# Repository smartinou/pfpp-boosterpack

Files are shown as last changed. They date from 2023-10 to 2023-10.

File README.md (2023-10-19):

# pfpp-rtcc-boosterpack
A boosterpack-compatible board for pfpp project.

This board holds a battery-backup'ed precision RTCC. It's main duty is to keep the time of the day and manage alarms that are set for feeding your pet.

on top of an RTCC, it also holds a MicroSD card cage, and a TB6612 motor controller. The MicroSD card can be used for logging events. The motor controller is used to activate the feeder.

This project was originally built for the EK-TM4C129EXL development board, on boosterpack2 location. It should work on any BoosterPack-compatible interface.

## GPIO Mapping

GPIO match for various development boards.

### EK-TM4C129EXL

J1
Pin | MCU Pin | BoosterPack Schematic
--- | --- | ---
1 | +3.3V | +3.3V
2 | PD2 | NC
3 | PP0 | NC
4 | PP1 | NC
5 | See JP4 | SPI_SDC_CSn
6 | See JP5 | NC
7 | PQ0 | SPI_CLK
8 | PP4 | NC
9 | PN5 | NC
10 | PN4 | NC

J2
Pin | MCU Pin | BoosterPack Schematic
--- | --- | ---
1 | GND | GND
2 | PM7 | NC
3 | PP5 | NC
4 | PA7 | SD_DET
5 | Reset | NC
6 | PQ2/PA3 | SPI_MOSI
7 | PQ3/PA2 | SPI_MISO
8 | PP3 | RTCC_INTn
9 | PQ1 | SPI_RTCC_CSn
10 | PM6 | AIN2

J3
Pin | MCU Pin | BoosterPack Schematic
--- | --- | ---
1 | +5V | NC
2 | GND | GND
3 | PB4 | NC
4 | PB5 | NC
5 | PK0 | NC
6 | PK1 | NC
7 | PK2 | NC
8 | PK3 | NC
9 | PA4 | NC
10 | PA5 | NC

J4
Pin | MCU Pin | BoosterPack Schematic
--- | --- | ---
1 | PG1 | PWMB
2 | PK4 | PWMA
3 | PK5 | NC
4 | PM0 | NC
5 | PM1 | NC
6 | PM2 | BIN2
7 | PH0 | BIN1
8 | PH1 | STBYn
9 | PK6 | AIN1
10 | PK7 | RTCC_RST

### EK-TM4C123GXL

**Even if the board was 1st developed for the EK-TM4C129EXL, the GPIO pin matching for the EK-TM4C123GXL corresponds to the symbols in the schematic.**

Pin | J1 MCU Pin | J1 BoosterPack Schematic | J3 MCU Pin | J3 BoosterPack Schematic
--- | --- | --- | --- | ---
1 | +3.3V | +3.3V | +5V | NC
2 | PB5 | NC | GND | GND
3 | PB0 | NC | PB4 | NC
4 | PB1 | NC | PB5 | NC
5 | PE4 | SPI_SDC_CSn | PK0 | NC
6 | PE5 | NC | PK1 | NC
7 | PB4 | SPI_CLK | PK2 | NC
8 | PA5 | NC | PK3 | NC
9 | PA6 | NC | PA4 | NC
10 | PA6 | NC | PA5 | NC

Pin | J4 MCU Pin | J4 BoosterPack Schematic | J2 MCU Pin | J2 BoosterPack Schematic
--- | --- | --- | --- | ---
1 | PF2 | PWMB | GND | GND
2 | PF3 | PWMA | PB2 | NC
3 | PB3 | NC | PB0 | NC
4 | PC4 | NC | PF0 | SD_DET
5 | PC5 | NC | Reset | NC
6 | PC6 | BIN2 | PB7 | SPI_MOSI
7 | PC7 | BIN1 | PB6 | SPI_MISO
8 | PD6 | STBYn | PA4 | RTCC_INTn
9 | PD7 | AIN1 | PA3 | SPI_RTCC_CSn
10 | PC4 | RTCC_RST | PA2 | AIN2

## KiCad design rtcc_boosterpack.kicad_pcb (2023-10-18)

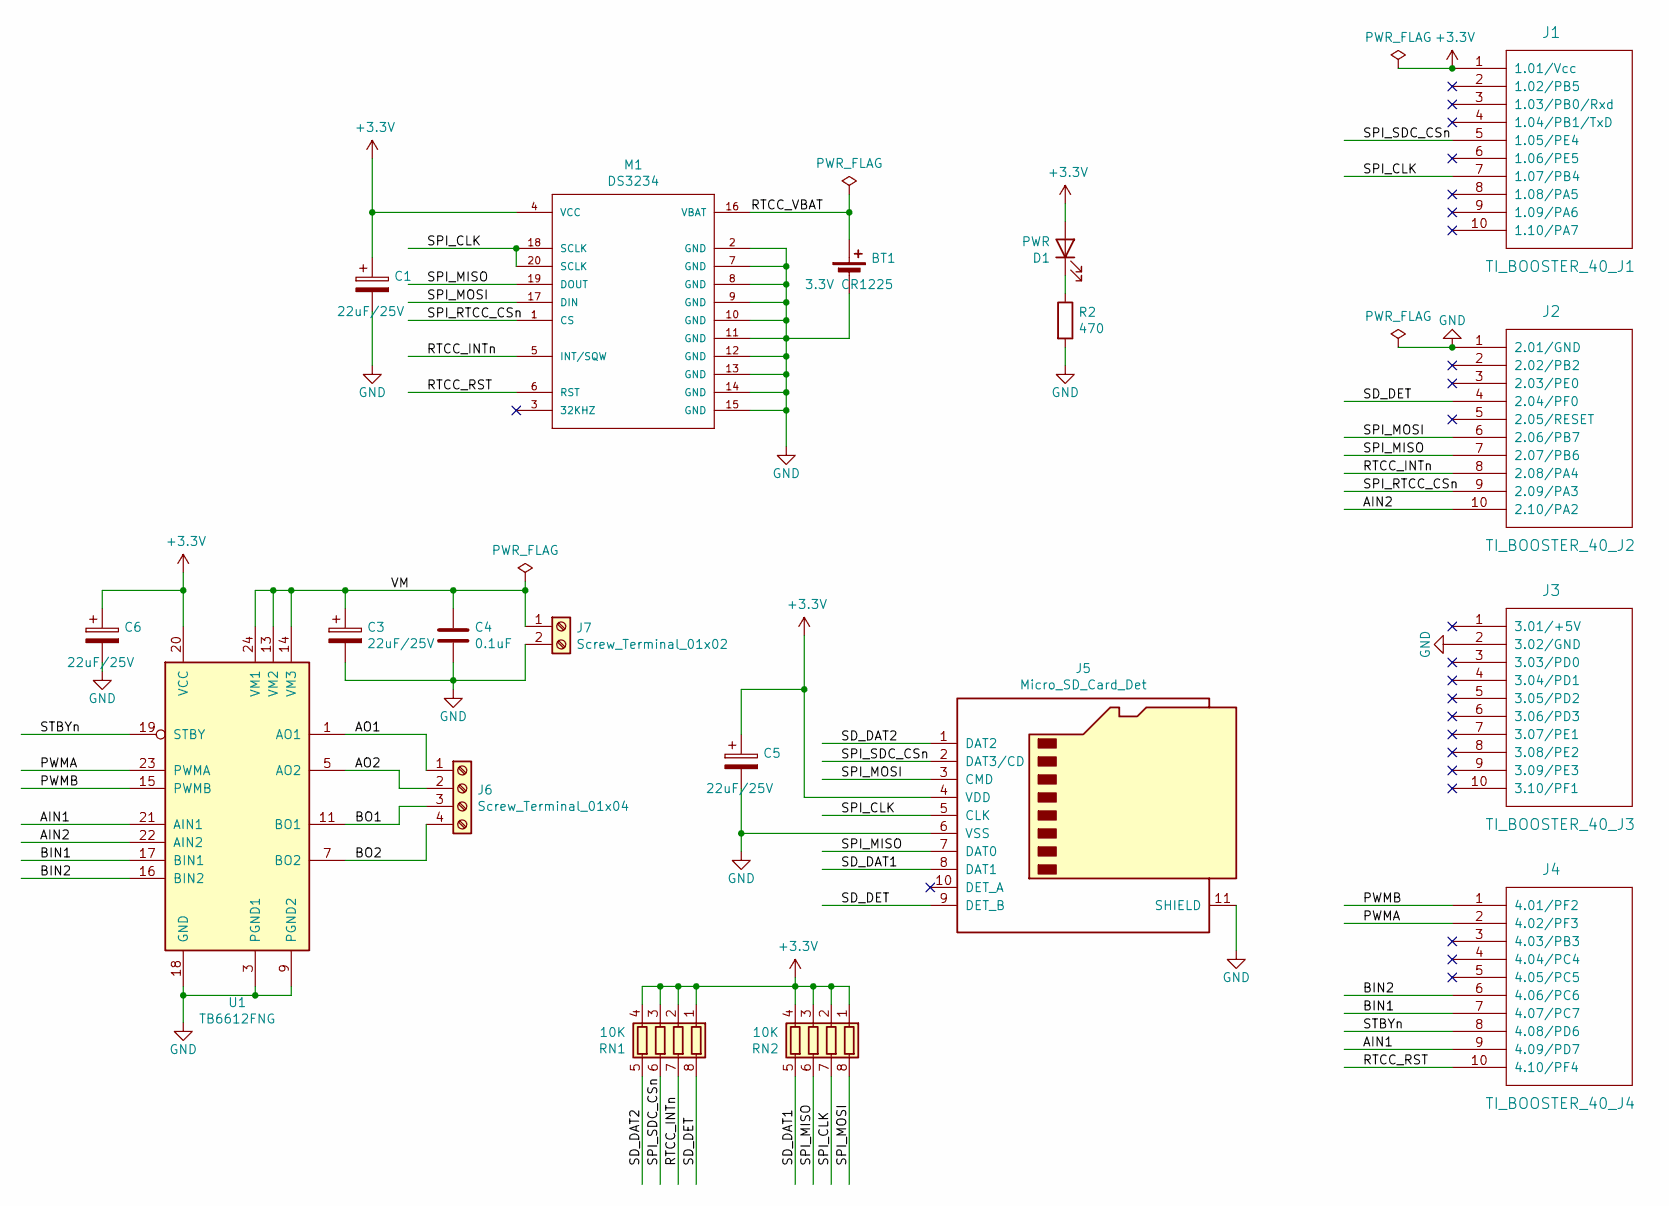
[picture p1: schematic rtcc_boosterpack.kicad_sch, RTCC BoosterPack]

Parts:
BT1: 3.3V CR1225; BatteryHolder_Keystone_3000_1x12mm; LCSC N/A
C1, C3, C5, C6: 22uF/25V; C_0805_2012Metric_Pad1.18x1.45mm_HandSolder; LCSC C45783
C4: 0.1uF; C_0603_1608Metric_Pad1.08x0.95mm_HandSolder; LCSC C14663
D1: PWR; LED_0603_1608Metric_Pad1.05x0.95mm_HandSolder; LCSC C2286
J1: TI_BOOSTER_40_J1; PinHeader_1x10_P2.54mm_Vertical; LCSC N/A
J2: TI_BOOSTER_40_J2; PinHeader_1x10_P2.54mm_Vertical; LCSC N/A
J3: TI_BOOSTER_40_J3; PinHeader_1x10_P2.54mm_Vertical; LCSC N/A
J4: TI_BOOSTER_40_J4; PinHeader_1x10_P2.54mm_Vertical; LCSC N/A
J5: Micro_SD_Card_Det; SF-MICRO-SD-PFPP; LCSC C105419
J6: Screw_Terminal_01x04; TerminalBlock_TE_282834-4_1x04_P2.54mm_Horizontal; LCSC C474922
J7: Screw_Terminal_01x02; TerminalBlock_TE_282834-2_1x02_P2.54mm_Horizontal; LCSC C474920
M1: DS3234; SOP-20_7.5x12.8mm_P1.27mm; LCSC C143318
R2: 470; R_0603_1608Metric_Pad0.98x0.95mm_HandSolder; LCSC C23179
RN1, RN2: 10K; R_Array_Convex_4x0603; LCSC C29718
U1: TB6612FNG; TSSOP-24_6.1x7.8mm_P0.65mm; LCSC C141517

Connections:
+3V3: C1.1, C5.1, C6.1, D1.2 (A), J1.1 (1.01/Vcc), J5.4 (VDD), M1.4 (VCC), RN1.1 (R1.1), RN1.2 (R2.1), RN1.3 (R3.1), RN1.4 (R4.1), RN2.1 (R1.1), RN2.2 (R2.1), RN2.3 (R3.1), RN2.4 (R4.1), U1.20 (VCC)
/AIN1: J4.9 (4.09/PD7), U1.21 (AIN1)
/AIN2: J2.10 (2.10/PA2), U1.22 (AIN2)
/AO1: J6.1, U1.1 (AO1), U1.2 (AO1)
/AO2: J6.2, U1.5 (AO2), U1.6 (AO2)
/BIN1: J4.7 (4.07/PC7), U1.17 (BIN1)
/BIN2: J4.6 (4.06/PC6), U1.16 (BIN2)
/BO1: J6.3, U1.11 (BO1), U1.12 (BO1)
/BO2: J6.4, U1.7 (BO2), U1.8 (BO2)
/PWMA: J4.2 (4.02/PF3), U1.23 (PWMA)
/PWMB: J4.1 (4.01/PF2), U1.15 (PWMB)
/RTCC_INTn: J2.8 (2.08/PA4), M1.5 (INT/SQW), RN1.7 (R2.2)
/RTCC_RST: J4.10 (4.10/PF4), M1.6 (RST)
/RTCC_VBAT: BT1.1 (+), M1.16 (VBAT)
/SD_DAT1: J5.8 (DAT1), RN2.5 (R4.2)
/SD_DAT2: J5.1 (DAT2), RN1.5 (R4.2)
/SD_DET: J2.4 (2.04/PF0), J5.9 (DET_B), RN1.8 (R1.2)
/SPI_CLK: J1.7 (1.07/PB4), J5.5 (CLK), M1.18 (SCLK), M1.20 (SCLK), RN2.7 (R2.2)
/SPI_MISO: J2.7 (2.07/PB6), J5.7 (DAT0), M1.19 (DOUT), RN2.6 (R3.2)
/SPI_MOSI: J2.6 (2.06/PB7), J5.3 (CMD), M1.17 (DIN), RN2.8 (R1.2)
/SPI_RTCC_CSn: J2.9 (2.09/PA3), M1.1 (CS)
/SPI_SDC_CSn: J1.5 (1.05/PE4), J5.2 (DAT3/CD), RN1.6 (R3.2)
/STBYn: J4.8 (4.08/PD6), U1.19 (STBY)
/VM: C3.1, C4.1, J7.1, U1.13 (VM2), U1.14 (VM3), U1.24 (VM1)
GND: BT1.2 (-), C1.2, C3.2, C4.2, C5.2, C6.2, J2.1 (2.01/GND), J3.2 (3.02/GND), J5.6 (VSS), J5.11 (SHIELD), J7.2, M1.2 (GND), M1.7 (GND), M1.8 (GND), M1.9 (GND), M1.10 (GND), M1.11 (GND), M1.12 (GND), M1.13 (GND), M1.14 (GND), M1.15 (GND), R2.2, U1.3 (PGND1), U1.4 (PGND1), U1.9 (PGND2), U1.10 (PGND2), U1.18 (GND)
unnamed: D1.1 (K), R2.1

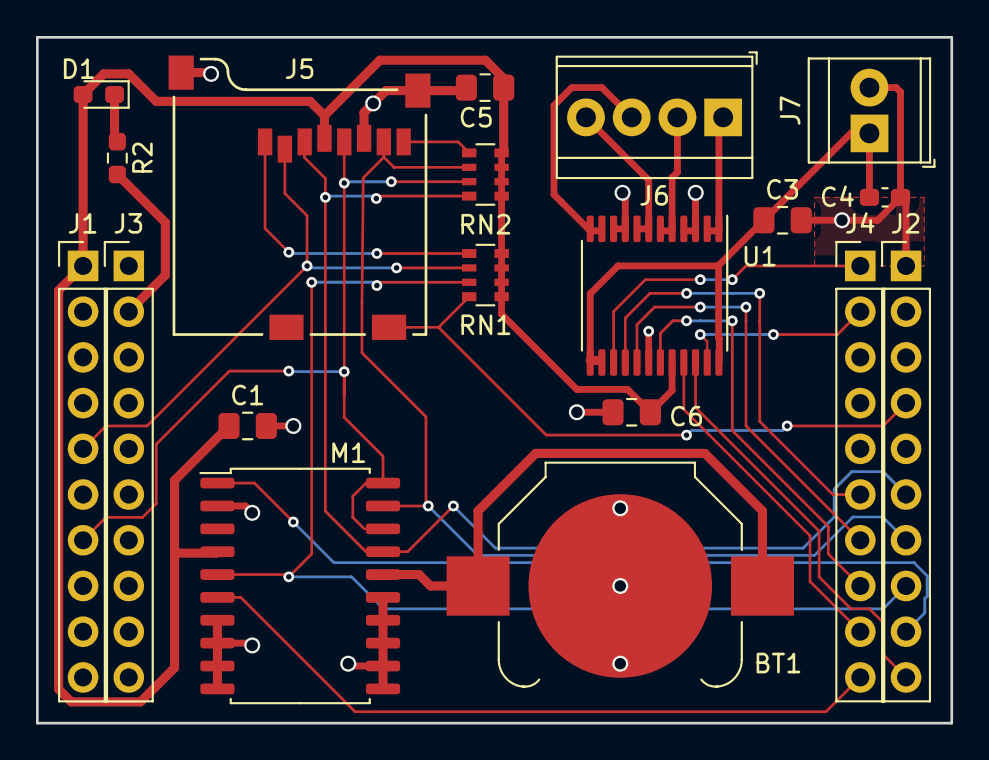
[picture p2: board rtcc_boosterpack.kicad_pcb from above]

Board: 2 copper layers, 50.8 x 38.1 mm, 19 parts (0 on the bottom side), 26 nets.

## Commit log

2023-10-17 Initial commit of project files done using KiCad 5.x
    [tm4c129_BoosterPack2.kicad_pcb, tm4c129_BoosterPack2.sch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]
2023-10-17 Convert to KiCad v7.0.8
    [rtcc_boosterpack.kicad_pcb, rtcc_boosterpack.sch, tm4c129_BoosterPack2.kicad_pcb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]
2023-10-17 Converts schematic to KiCad 7.0.8
    [rtcc_boosterpack.kicad_sch, rtcc_boosterpack.sch]
2023-10-17 Fixes D1 polarity.
    [rtcc_boosterpack.kicad_pcb, rtcc_boosterpack.kicad_sch]
2023-10-17 Updates revision number in design sheet.
    [rtcc_boosterpack.kicad_sch]
2023-10-18 Updates version printed on bottom silk screen.
    [rtcc_boosterpack.kicad_pcb]
2023-10-19 Update README.md
    Finishes the GPIO mapping of the EK-TM4C123GXL dev board.
